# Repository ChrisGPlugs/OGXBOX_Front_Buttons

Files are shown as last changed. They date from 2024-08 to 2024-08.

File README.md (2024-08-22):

Orginal Xbox Front button board. 
Recreated in KiCad based off the Board design of the Gerbers from Thomas Heath
Track Layout redesigned to be almost the same as stock on the back.
All graphics replaced and outline adjusted with curves.

Three options are uploaded.
1. Has the HDD and LAN leds added to it with locations to add resistors. These are 0603 SMD's 
2. Is same as stock with the Tracks on the back.
3. Same as stock but with the layers swapped so the tracks are on the front for if you are worried about tracks getting exposed and shorting things out.
  
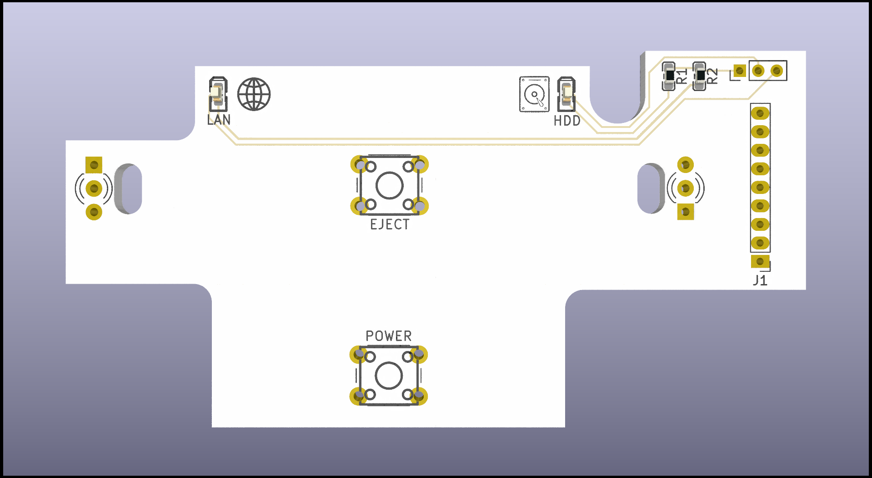
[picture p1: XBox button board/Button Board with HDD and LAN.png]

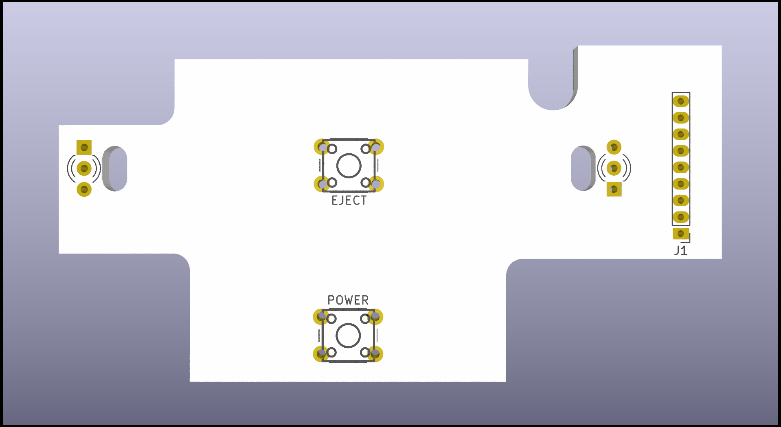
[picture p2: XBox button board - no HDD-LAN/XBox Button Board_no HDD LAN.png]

I've done a drawing to make a self adhesive vinyl sticker. This is to be affixed to the back so that it is the same as stock. 
I have not found a suitable suplier yet. 

if I cannot get stickers I will probably use 50mm wide PVC tape on the back of mine and then cut it out with a craft knife or exacto blade

These Tactile switches have the correct measurements. Tact Button Switch 6x6x4.3mm
https://www.mouser.co.uk/ProductDetail/Omron-Electronics/B3F-1000?qs=lK7M36XCk6JQHckSc1xIsg%3D%3D
https://www.digikey.co.uk/en/products/detail/omron-electronics-inc-emc-div/B3F-1000/33150

The connector that plugs into the motherboard is JST PHD 2mm 10 way connector. https://www.jst.co.uk/productSeries.php?pid=88&cat=30
I bought some of these off ali express. You could solder them on directly or use another suitable connector.
https://www.aliexpress.com/item/1005005940137789.html?spm=a2g0o.order_list.order_list_main.17.1e5b1802rfvPIm

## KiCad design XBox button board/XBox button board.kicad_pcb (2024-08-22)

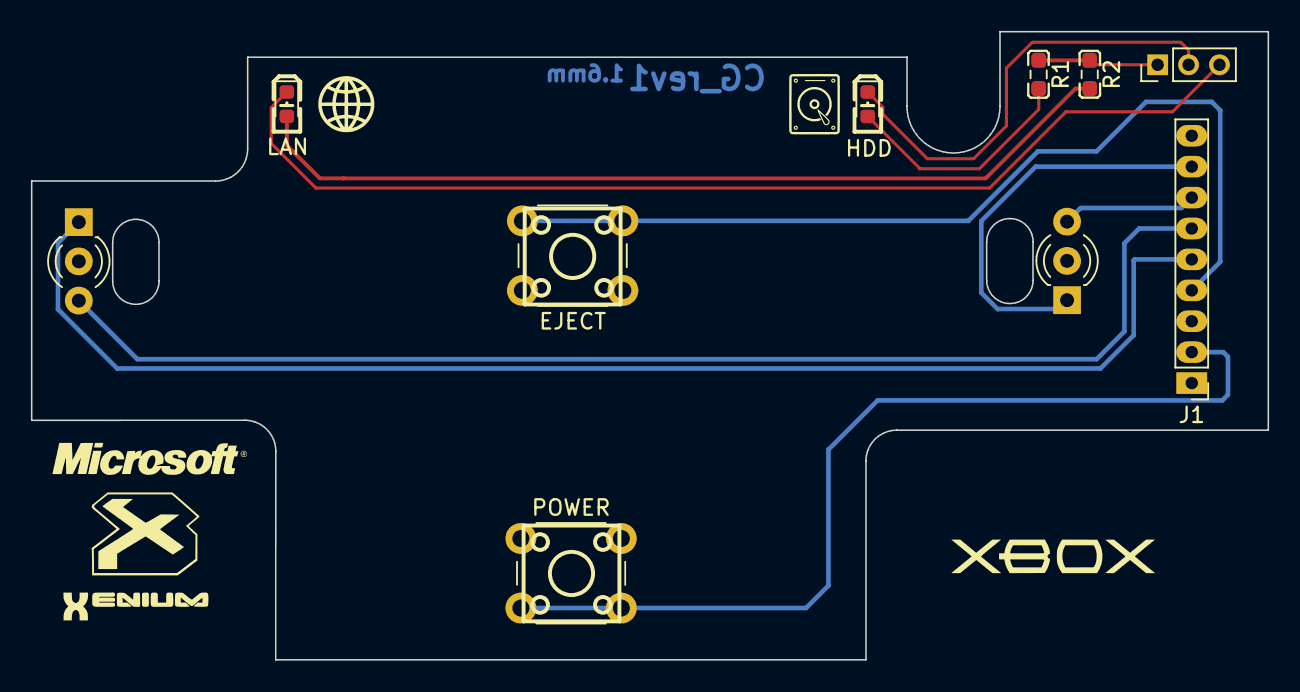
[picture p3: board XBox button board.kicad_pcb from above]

Board: 2 copper layers, 80.0 x 40.6 mm, 11 parts (0 on the bottom side), 12 nets.

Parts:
D1: LED_Dual_AKA - LEFT; LED_D3.0mm-3
D2: LED_Dual_AKA - Right; LED_D3.0mm-3
EJECT: SW_Push-EJECT; SW_PUSH_6mm_H4.3mm
G: LOGO
HDD_LED1: Blue_56mcd_0603; LED_0603_1608Metric
J1: Conn_01x09_Pin; PinHeader_1x09_P2.00mm_Vertical
J2: Conn_01x03; PinHeader_1x03_P2.00mm_Vertical
LAN_LED1: Red_100mcd_0603; LED_0603_1608Metric
POWER: SW_Push Power; SW_PUSH_6mm_H4.3mm
R1, R2: 100_0603; R_0603_1608Metric_Pad0.98x0.95mm_HandSolder

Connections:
GND: D1.2 (K), D2.2 (K), EJECT.1, J1.1, J1.3, POWER.1
unnamed: D1.1 (A1), J1.5
unnamed: D1.3 (A2), J1.6
unnamed: D2.1 (A1), J1.8
unnamed: D2.3 (A2), J1.7
unnamed: HDD_LED1.2 (A), R1.2
unnamed: HDD_LED1.1 (C), J2.2
unnamed: J1.2, POWER.2
unnamed: EJECT.2, J1.4
unnamed: J2.1, R1.1, R2.1
unnamed: J2.3, LAN_LED1.1 (C)
unnamed: LAN_LED1.2 (A), R2.2

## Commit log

2024-07-06 First rev of board
    First rev of board with HDD and LAN led
    [XBox button board-B_Cu.gbr, XBox button board-B_Mask.gbr, XBox button board-B_Paste.gbr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]
2024-07-06 Cut Lines healed
    PCB was showing the cut lines a bit strangely on the preview. Healed the lines and all seems ok now
    [XBox button board-B_Cu.gbr, XBox button board-B_Mask.gbr, XBox button board-B_Paste.gbr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]
2024-07-06 NO HDD and LAN Leds
    removed the HDD and Lan LEDs
    [XBox button board_no_LAN-HDD-B_Cu.gbr, XBox button board_no_LAN-HDD-B_Mask.gbr, XBox button board_no_LAN-HDD-B_Paste.gbr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]
2024-07-06 Renders of the two boards
    A coupe of pics for reference
2024-07-06 Stock Board added with all tracks on the front
    Did another Variant that has the tracks on the front only to prevent short circuits if tracks are scratched and exposed
    [XBox button board_no_LAN-HDD_all tracks front-B_Cu.gbr, XBox button board_no_LAN-HDD_all tracks front-B_Mask.gbr, XBox button board_no_LAN-HDD_all tracks front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]
2024-08-05 Minor image adjustment
    moved some graphics
    [XBox button board-B_Cu.gbr, XBox button board-B_Mask.gbr, XBox button board-B_Paste.gbr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]
2024-08-05 Added Zips of the gerbers
    zipped the gerbers for easy download
2024-08-22 updated silkscreens
    removed logos from silk print area
    [XBox button board-B_Cu.gbr, XBox button board-B_Mask.gbr, XBox button board-B_Paste.gbr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]
